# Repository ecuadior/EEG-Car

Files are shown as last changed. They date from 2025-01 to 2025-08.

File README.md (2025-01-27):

# EEG-Car
Project on a small car being controlled by ones brain wave 

UPDATES will be weekly/bi-weekly depends on school

  Currently working on the project I'll be posting the steps I've done to create this project. I'll use microcontrollers to read the brain wave and move the car. The plan is to create a PCB for the vehicle.

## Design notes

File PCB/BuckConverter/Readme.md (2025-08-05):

Buck converter that will be used to power the esp 32 board
9 to 3.3V
current max output: 300mA

WHile testing out the pcb for the buck converter it was found out there was no output volatge/current. Debugging was done with a multimeter testing whih component recive voltage and testing if there is any short circuirt by testing contiuity. 
During the test it was found there was no error short shirt becasue the contituty was acting cirrectly for all componet. While looking for components volatge it was found everything to the right of the IC was recing voltge but ervrything to the left wasnt recving volatge. I speculate it could be the EN pin connected to the voolatge divder, in which the path is to small that signal is not passing. More so, the data sheet for LMR36503 highlits that in some case the EN pin should be connected starigh to VIN. 

Another possible issue is the instalation of yhe inductor to the pcb it might have damage something because when testing the connectvity of where the inductor will be place there is no noise(indacting contiuity is good) but this was with testing on the pcb with no componet. Howeverm doing the same test with the pcb with componets continutyi was found beteern the two ends of the the inductor. 
Image below is version 1 of the buck converter


Buck Converter V2 during testing showcased outstanding result,s in which it was able to deliver the optimal output and was able to withstand the increase of temparutre during usage.

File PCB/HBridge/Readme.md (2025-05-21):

H bridge used to control the motor that will move the car. 

Schematic Image


PCB Image:


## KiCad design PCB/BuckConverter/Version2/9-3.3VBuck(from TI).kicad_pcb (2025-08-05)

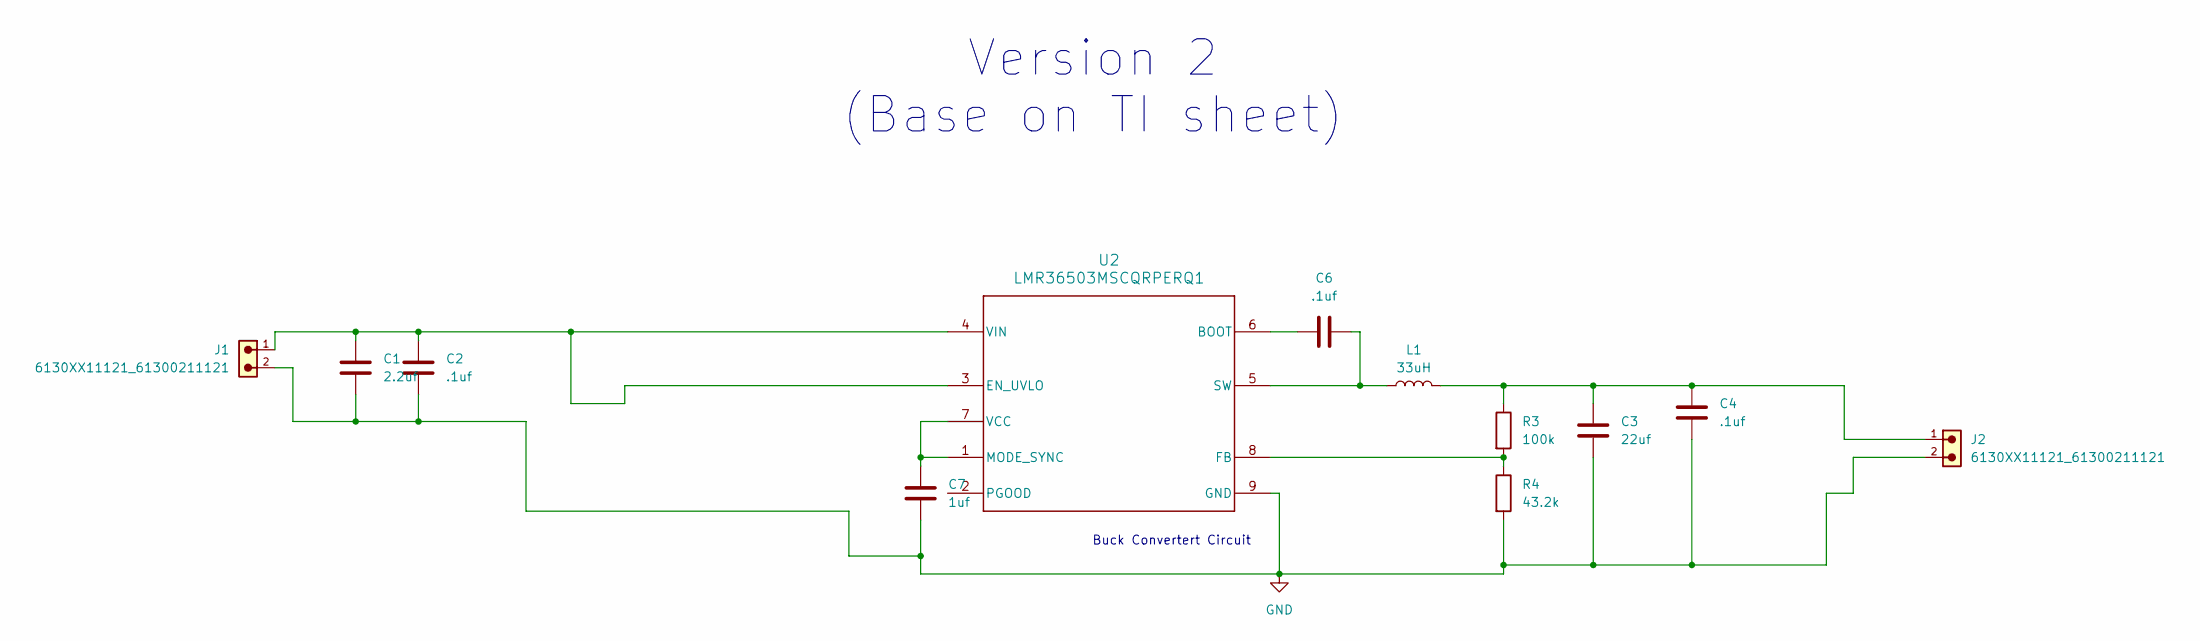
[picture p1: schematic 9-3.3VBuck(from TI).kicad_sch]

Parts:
C1: 2.2uf; C_0805_2012Metric; LCSC C125847
C2, C4, C6: .1uf; C_0603_1608Metric; LCSC C30926
C3: 22uf; CAPC3225X270N; LCSC C126614
C7: 1uf; C_0603_1608Metric; LCSC C93816
J1, J2: 6130XX11121_61300211121; 61300211121
L1: 33uH; IND_SRR6038-330Y; LCSC C2041395
R3: 100k; RESC1607X60N; LCSC C14675
R4: 43.2k; R_0603_1608Metric
U2: LMR36503MSCQRPERQ1; RPE0009A; LCSC C3190190

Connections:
GND: C1.2, C2.2, C3.2, C4.2, C7.2, J1.2, J2.2, R4.2, U2.9 (GND)
unnamed: C3.1, C4.1, J2.1, L1.2, R3.1
unnamed: C6.1, U2.6 (BOOT)
unnamed: C1.1, C2.1, J1.1, U2.3 (EN_UVLO), U2.4 (VIN)
unnamed: R3.2, R4.1, U2.8 (FB)
unnamed: C7.1, U2.1 (MODE_SYNC), U2.7 (VCC)
unnamed: C6.2, L1.1, U2.5 (SW)

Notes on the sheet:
Buck Convertert Circuit
Version 2 (Base on TI sheet)

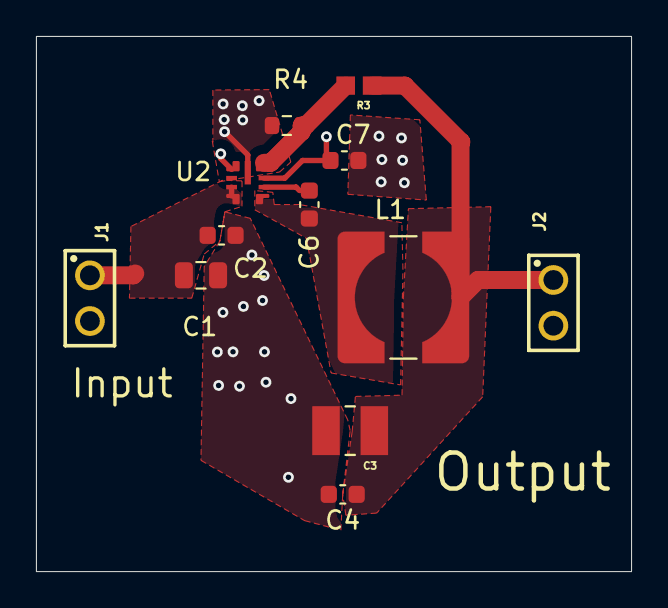
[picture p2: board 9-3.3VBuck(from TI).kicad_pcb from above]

Board: 4 copper layers, 33.1 x 29.7 mm, 12 parts (0 on the bottom side), 7 nets.

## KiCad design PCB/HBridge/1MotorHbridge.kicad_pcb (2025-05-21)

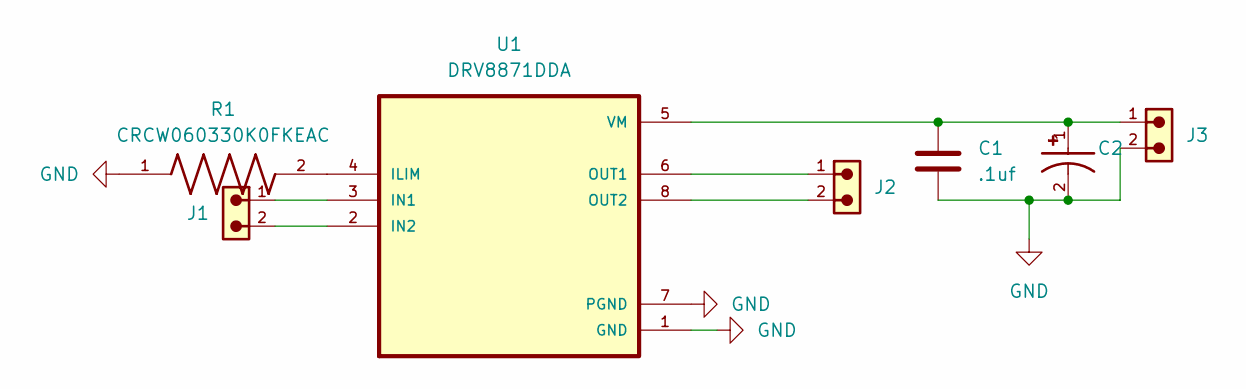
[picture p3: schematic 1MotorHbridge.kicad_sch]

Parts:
C1: .1uf; C_0603_1608Metric
C2: EEHZC1V470P; CAP_EEHZC1V470P; PARTREV 30-Sep-20; DigiKey_Part_Number P15473TR-ND
J1, J2, J3: 6130XX11121_61300211121; 61300211121
R1: CRCW060330K0FKEAC; RESC1608X55N
U1: DRV8871DDA; VREG_LM5017MR_NOPB

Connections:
GND: C1.2, C2.2, J3.2, R1.1, U1.1 (GND), U1.7 (PGND)
unnamed: R1.2, U1.4 (ILIM)
unnamed: J1.1, U1.3 (IN1)
unnamed: J1.2, U1.2 (IN2)
unnamed: J2.1, U1.6 (OUT1)
unnamed: J2.2, U1.8 (OUT2)
unnamed: C1.1, C2.1, J3.1, U1.5 (VM)

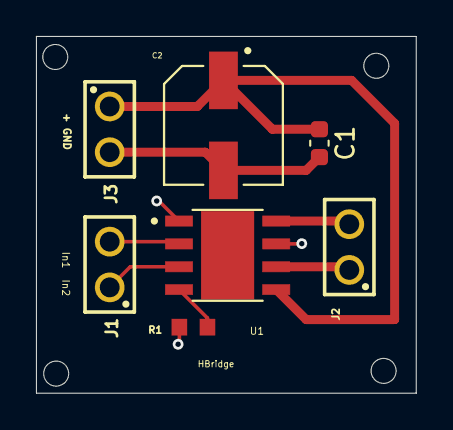
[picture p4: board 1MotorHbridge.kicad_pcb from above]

Board: 2 copper layers, 21.1 x 19.8 mm, 7 parts (0 on the bottom side), 7 nets.

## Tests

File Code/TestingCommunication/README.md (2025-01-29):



The code here is a prototype of how the final project will look like.

Testing if 2 ESP-32 can communicate via ESP-NOW, in which the Master ESP-32 will read data from a IR sensor and the data would be sent to the Slave ESP-32.
The Slave ESP-32 would take the data from the Master ESP-32 and would use the input(0/1) to decide if the motor moves foward or stop.

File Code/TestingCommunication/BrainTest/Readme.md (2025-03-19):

The code posted folder in this field is used to test the MindFlex communication with the esp-32 and to see if the project is possible 

When it comes to finding and gathering data to see how the attention values correlate to me focusing on a task multiple tests were done.

The first test was my relaxing state to demonstrate which values show I'm relaxing. In this test, I had my eyes open and listened to music, and sometimes, I would close my eyes or tap my fingers or feet to the beat of the music.


The image above shows the attention value of 36-46 is my relaxed state and anything else would be noise. The cause of this noise could be due to during this test I was focusing to find a song, which might have led to numbers higher than 46. 

The next test involved me reading a book for around 30 minutes. When I read something interesting, all my focus goes into the book. To ensure I was concentrating, I wore noise-canceling headphones and listened to J-pop, which helps me focus. However, during the last 10 to 15 minutes, I lost focus, which caused a spike in values corresponding to my relaxed state.

Thus, there are two graphs below—one including the error and one without it. I believe the graph without the error is correct because the loss of focus likely began 10 to 15 minutes before the 30-minute mark.





Therefore, I believe attention values between 64 and 81 demonstrate that I'm focusing, or any number higher than 64, as I believe values above 81 also indicate focus.

Another test was conducted to observe my attention values while playing video games. For this test, I played Valorant for about an hour.

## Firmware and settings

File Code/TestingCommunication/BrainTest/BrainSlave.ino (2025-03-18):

//Slave communication
#include <esp_now.h>
#include <WiFi.h> 
#include <Brain.h>

const int ForwardPin = 13;       // H-bridge forward control pin
const int BackwardPin = 12;      // H-bridge backward control pin
const int pwmFreq = 5000;        // Frequency for PWM (5kHz)
const int pwmResolution = 8;    // Resolution for PWM (0-255)


typedef struct struct_message //recive data should be same as sender
{
  byte Command;
}struct_message;

struct_message ReciveData;
bool newDataReceived = false; 

//Function called when recive data
void OnDataRecv(const uint8_t * mac, const uint8_t *incomingData, int len)
{
  //copy info incomingData to Recivedata
  memcpy(&ReciveData, incomingData, sizeof(ReciveData));
  newDataReceived = true; // Flag to indicate new data has been received
}


void setup() {
  Serial.begin(115200);
  WiFi.mode(WIFI_STA); //set as wifi station

  //Intiliaze ESP-NOW:
  if(esp_now_init() != ESP_OK)
  {
    Serial.println("Error initliazing ESP-NOW");
    return;
  }

  // Once ESPNow is successfully Init, we will register for recv CB to
  // get recv packer info
  esp_now_register_recv_cb(esp_now_recv_cb_t(OnDataRecv));

  ledcAttach(ForwardPin, pwmFreq, pwmResolution);
  ledcAttach(BackwardPin, pwmFreq, pwmResolution);

}

void loop() {
   if (newDataReceived) {
    newDataReceived = false; // Reset flag
    if(ReciveData.Command > 64) //nothing dtected
    {
      ForwardDirection();
      Serial.println("Going Foward");
    } 
    else if(ReciveData.Command < 64)
    {
      StopMotor();// something deteced
      Serial.println("Stopping");
    }
   }
  delay(2000);
}
void ForwardDirection() {
  ledcWrite(ForwardPin, 200); // Set forward pin PWM duty cycle
  ledcWrite(BackwardPin, 0);  // Ensure backward pin is off
  //Serial.println("Motor Moving Forward");
}
void BackwardDirection()
{
  ledcWrite(BackwardPin, 120); // set backward pwm duty cycle
  ledcWrite(ForwardPin, 0); // Ensure forward pin is off
}
void StopMotor() {
  ledcWrite(ForwardPin, 0);   // Stop forward pin
  ledcWrite(BackwardPin, 0);  // Stop backward pin
  //Serial.println("Motor Stopped");
}

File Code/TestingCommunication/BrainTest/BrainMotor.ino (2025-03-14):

// This will be a test to see if when I'm focusing, it would cause the motor to spin
// Purpose use the attention value which represnt focus beacsue most stable
//This will be done with 1 micrcontroller and is a test case to see if its possible to do it with 2 micrcontroller

#include <Brain.h>
HardwareSerial mySerial(1);
Brain brain(mySerial);

//H-Bridge
const int ForwardPin = 13;       // H-bridge forward control pin
const int BackwardPin = 12;      // H-bridge backward control pin
const int pwmFreq = 5000;        // Frequency for PWM (5kHz)
const int pwmResolution = 8;    // Resolution for PWM (0-255)

void setup() {
  Serial.begin(115200);
  mySerial.begin(9600, SERIAL_8N1, 17, 16); // TX=16, RX=17 (change as needed)
  

   // Set up PWM channels and attach them to pins
  ledcAttach(ForwardPin, pwmFreq, pwmResolution);
  ledcAttach(BackwardPin, pwmFreq, pwmResolution);
  

}

void loop() {
 if (brain.update()) {
    Serial.println(brain.readAttention());
    byte focus = brain.readAttention();
    if(focus>=60) // Means I'm fcousing on something. Dont know full range but knows its larger than 60 
    {
      ForwardDirection();
    }
    else
    {
      StopMotor();
    }
  }

}

void ForwardDirection() {
  ledcWrite(ForwardPin, 200); // Set forward pin PWM duty cycle
  ledcWrite(BackwardPin, 0);  // Ensure backward pin is off
  //Serial.println("Motor Moving Forward");
}
void BackwardDirection()
{
  ledcWrite(BackwardPin, 120); // set backward pwm duty cycle
  ledcWrite(ForwardPin, 0); // Ensure forward pin is off
}
void StopMotor() {
  ledcWrite(ForwardPin, 0);   // Stop forward pin
  ledcWrite(BackwardPin, 0);  // Stop backward pin
  //Serial.println("Motor Stopped");
}

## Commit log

2025-01-29 upload code for slave esp32
2025-07-17 Update and rename PCB/BuckConverter/Buck Converter.kicad_pcb to PCB/BuckConverter/Version1/Buck Converter.kicad_pcb
    [Buck Converter.kicad_pcb]
2025-07-17 Rename PCB/BuckConverter/Buck Converter.kicad_pro to PCB/BuckConverter/Version1/Buck Converter.kicad_pro
2025-07-17 Update and rename PCB/BuckConverter/Buck Converter.kicad_sch to PCB/BuckConverter/Version1/Buck Converter.kicad_sch
    [Buck Converter.kicad_sch]
2025-08-05 Buck convert V2
    [9-3.3VBuck(from TI).kicad_pcb, 9-3.3VBuck(from TI).kicad_sch]
